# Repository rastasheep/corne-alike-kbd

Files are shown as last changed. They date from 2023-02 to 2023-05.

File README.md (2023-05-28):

# Corne alike keyboard
Split keyboard with 3x6 column staggered keys, 3 keys thumb cluster, inspired by [Corne](https://github.com/foostan/crkbd).

## Features

- Designed from the ground up
- Wireless only (no TRRS connectors)
- JST battery connectors
- On/Off switch
- Kailh Choc Switch spacing
- Option to snap off 6th column (3x5 layout as option)
- No OLED module
- No Backlighting

## Repository Contents

- **/pcb** - Pcb design files, made with KiCad, grouped by version (.kicad_pro, .kicad_sch, .kicad_pcb)

## Versions

- **v1.0** - Initial version, Choc v1 switches, full feature set
- **v1.1** - Bug fix version, flip battery connector polarity, fix power input pin

## License Information

Corne alike is open source, released under the [MIT License](/LICENSE.md).

If you have any questions or concerns on licensing, please contact rastasheep@gmail.com.

Distributed as-is; no warranty is given.

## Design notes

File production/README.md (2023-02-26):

# Corne alike keyboard production files

These are the production files used for printing PCBs.

## License Information

Corne alike is open source, released under the [MIT License](/LICENSE.md).

If you have any questions or concerns on licensing, please contact rastasheep@gmail.com.

Distributed as-is; no warranty is given.

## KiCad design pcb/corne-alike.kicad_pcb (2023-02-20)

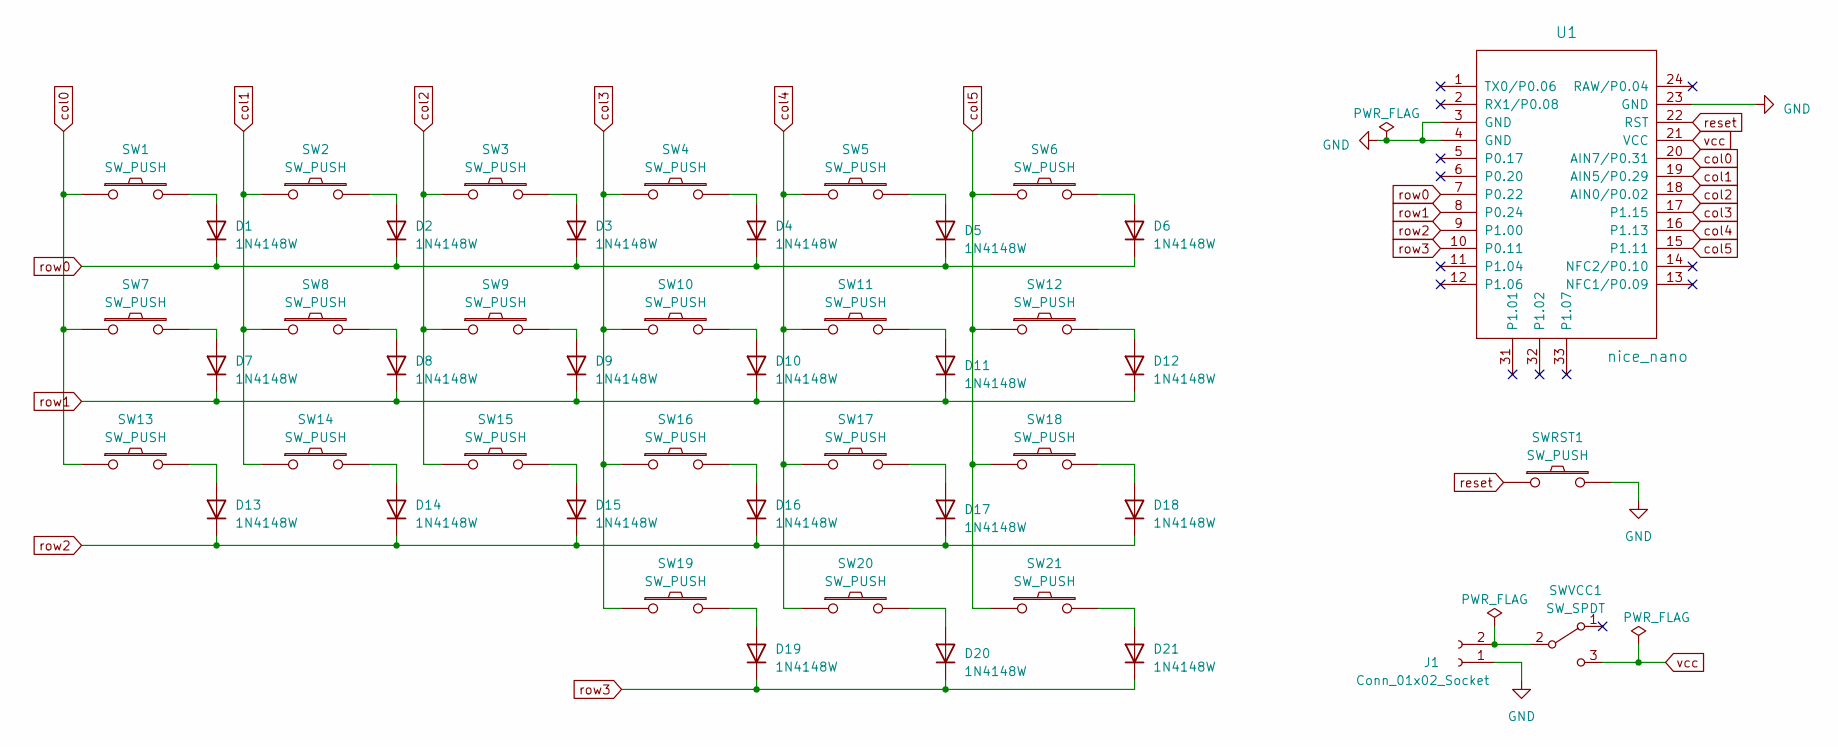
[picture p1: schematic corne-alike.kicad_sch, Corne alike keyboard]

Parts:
D1, D2, D3, D4, D5, D6, D7, D8, D9, D10, D11, D12, D13, D14, D15, D16, D17, D18, D19, D20, D21: 1N4148W; D_SOD-123
J1: Conn_01x02_Socket; JST_PH_S2B-PH-SM4-TB_1x02-1MP_P2.00mm_Horizontal
SW1, SW2, SW3, SW4, SW5, SW6, SW7, SW8, SW9, SW10, SW11, SW12, SW13, SW14, SW15, SW16, SW17, SW18, SW19, SW20, SW21: SW_PUSH; Kailh_PG1350
SWRST1: SW_PUSH; SW_TVBP06
SWVCC1: SW_SPDT; SW_EG1218
U1: nice_nano

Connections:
GND: J1.1, SWRST1.2, U1.3 (GND), U1.4 (GND), U1.23 (GND); also elsewhere on the board
unnamed 1: J1.2, SWVCC1.2 (B); also elsewhere on the board
unnamed: D1.2 (A), SW1.2
unnamed: D2.2 (A), SW2.2
unnamed: D3.2 (A), SW3.2
unnamed: D4.2 (A), SW4.2
unnamed: D5.2 (A), SW5.2
unnamed: D6.2 (A), SW6.2
unnamed: D7.2 (A), SW7.2
unnamed: D8.2 (A), SW8.2
unnamed: D9.2 (A), SW9.2
unnamed: D10.2 (A), SW10.2
unnamed: D11.2 (A), SW11.2
unnamed: D12.2 (A), SW12.2
unnamed: D13.2 (A), SW13.2
unnamed: D14.2 (A), SW14.2
unnamed: D15.2 (A), SW15.2
unnamed: D16.2 (A), SW16.2
unnamed: D17.2 (A), SW17.2
unnamed: D18.2 (A), SW18.2
unnamed: D19.2 (A), SW19.2
unnamed: D20.2 (A), SW20.2
unnamed: D21.2 (A), SW21.2
col0: SW1.1, SW7.1, SW13.1, U1.20 (AIN7/P0.31)
col1: SW2.1, SW8.1, SW14.1, U1.19 (AIN5/P0.29)
col2: SW3.1, SW9.1, SW15.1, U1.18 (AIN0/P0.02)
col3: SW4.1, SW10.1, SW16.1, SW19.1, U1.17 (P1.15)
col4: SW5.1, SW11.1, SW17.1, SW20.1, U1.16 (P1.13)
col5: SW6.1, SW12.1, SW18.1, SW21.1, U1.15 (P1.11)
reset: SWRST1.1, U1.22 (RST)
row0: D1.1 (K), D2.1 (K), D3.1 (K), D4.1 (K), D5.1 (K), D6.1 (K), U1.7 (P0.22)
row1: D7.1 (K), D8.1 (K), D9.1 (K), D10.1 (K), D11.1 (K), D12.1 (K), U1.8 (P0.24)
row2: D13.1 (K), D14.1 (K), D15.1 (K), D16.1 (K), D17.1 (K), D18.1 (K), U1.9 (P1.00)
row3: D19.1 (K), D20.1 (K), D21.1 (K), U1.10 (P0.11)
vcc: SWVCC1.3 (C), U1.21 (VCC)

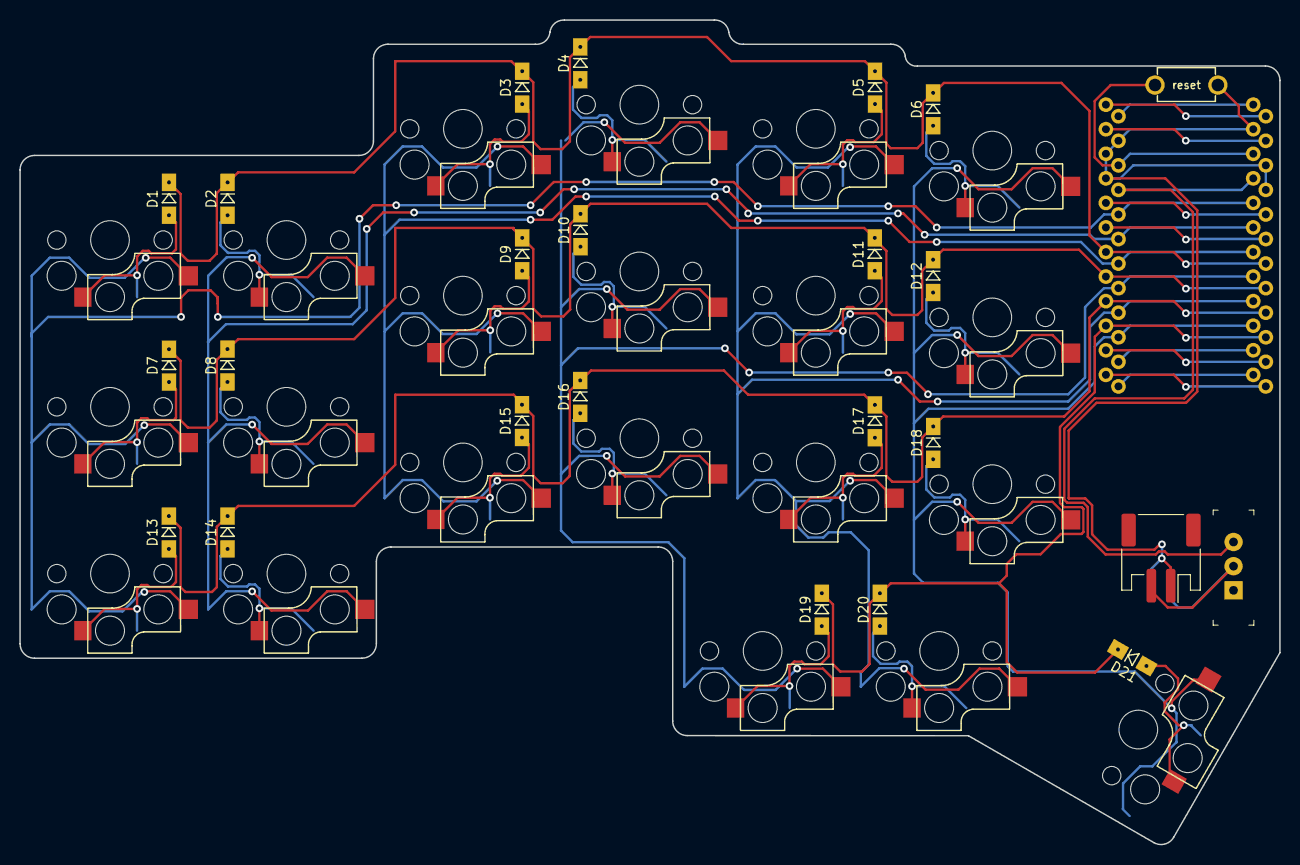
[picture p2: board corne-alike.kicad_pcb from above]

Board: 2 copper layers, 130.3 x 85.3 mm, 47 parts (1 on the bottom side), 35 nets.

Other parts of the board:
J1#2: Conn_01x02_Socket; JST_PH_S2B-PH-SM4-TB_1x02-1MP_P2.00mm_Horizontal

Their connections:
GND: J1#2.1; also elsewhere on the board
unnamed 1: J1#2.2; also elsewhere on the board

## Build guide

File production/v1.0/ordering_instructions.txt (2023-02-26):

design in panel, 1
single size, 85.35x130.301mm
number of layers, 2
material, fr-4
fr4-tg, tg 150-160
thickness, 1.6mm
min track spacing, 6mil
min hole size, 0.3mm
soldermask color, red
silkscreen color, white
edge connector, no
finish, hasl with lead
finished copper, 1oz
remove pcb identification number, yes

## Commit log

2023-02-16 Generate project, add schema
    [corne-alike.kicad_pcb, corne-alike.kicad_sch]
2023-02-16 Create footprint lib
2023-02-16 Associate footprints and generate pcb
    [corne-alike.kicad_pcb, corne-alike.kicad_sch]
2023-02-17 Place switches and create pcb shape
    [corne-alike.kicad_pcb]
2023-02-18 Connect switches and diodes
    [corne-alike.kicad_pcb]
2023-02-19 Connect rows and cols
    [corne-alike.kicad_pcb]
2023-02-19 Add bat connector, place reset, on/off and bat to pcb
    [corne-alike.kicad_pcb, corne-alike.kicad_sch]
2023-02-20 Clean up tracks, drc violations
    [corne-alike.kicad_pcb]
2023-02-20 Trace GND, clean up controller escape
    [corne-alike.kicad_pcb]
2023-02-20 Clean up tracks
    [corne-alike.kicad_pcb]
2023-02-21 Add teardrops, use hatched zone as gnd
2023-02-21 Remove diode labels
2023-02-21 Add board label and version
2023-02-26 Remove unnecessary silkscreen markings
2023-02-26 Organize repo, versions
    [corne-alike.kicad_sch]
2023-02-26 Prepare pcb for production
2023-05-28 Flip battery connector polarity, fix power input pin
    [corne-alike.kicad_sch]

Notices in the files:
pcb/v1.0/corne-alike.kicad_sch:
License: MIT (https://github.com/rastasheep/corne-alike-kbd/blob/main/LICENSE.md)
